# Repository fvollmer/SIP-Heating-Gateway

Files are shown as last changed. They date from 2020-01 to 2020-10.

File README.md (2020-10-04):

SIP Heating Gateway
====================


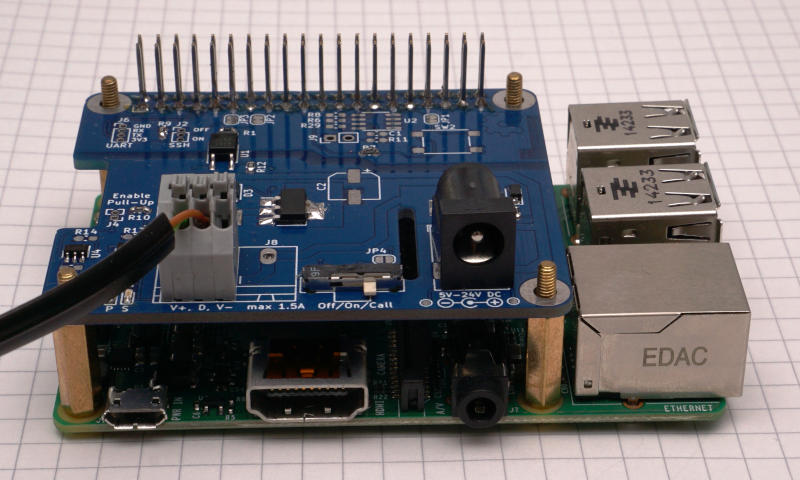
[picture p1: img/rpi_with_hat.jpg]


This device allows you to control the heating (or any other device) by calling in and using an interactive voice menu. In case of a power loss the last state will be restored as soon as the power is back. The software is build to survive unexpected power losses.

The heart of the system is a Raspberry pi with a custom hat to provide 12V to an external relay. On this Raspberry pi a custom embedded linux is used to to control the 12V via a small shell script. It connects via ethernet to the a SIP server (e.g. a fritzbox router or your isp). The heavy lifting for the SIP connection and the voice menu is done by asterisk, which uses the already mentioned shell script to switch a gpio pin. The linux system is build with buildroot and the hole image image is less than 200MB and boots in a few seconds.

The linux system on the raspberry pi is configured to use the micro sd card as read only storage. This should prevent damage on power failure. The only exception is a persitent partition, which is used to save the current state. This state will be restored in case of a power failure. The partition should also be safe from corruption due to the mount parameters and the infrequent writes.

## Usage

Connect Power (5V via micro-USB and 12V), ethernet and the output to the relay. After bootup the device accepts incoming calls.

Call the device,  wait until pickup and follow the voice instructions:
1. Enter the PIN and press `#`
2. Press `1` to turn the heating on, `2` to turn the heating off, `3` to get the status of the heating
3. Repeat step 2, or hang up

After a timeout the caller will be disconnected automatically.

```
                                               5V (micro USB)
                                                |
                                                v
+-----------------+                      +----------------+              +----------+
| router / switch | SIP (over ethernet)  | Raspberry Pi   | 12V Switched | Relay of |
| e.g. fritzbox   |<-------------------->| (with 12V hat) |------------->| heating  |
+-----------------+                      +----------------+              +----------+
                                                ^
                                                |
                                              12 V
```

## Configuration
The custom embedded system is based on buildroot. The behaviour at a call is controlled by [Asterisk](https://www.asterisk.org/). There are two main configuration files:
 * `/etc/asterisk/sip.conf`
   SIP server configuration
 * `/etc/asterisk/extensions.conf`
   Dialplan (phone menu, pin)

The configuration files can be adjusted by changing the files of the overlay (`br-external/board/raspberrypi-heating-control/rootfs-overlay`). Asterisk is configured to only use a minimal amount of modules. Modify `/etc/asterisk/modules.conf` if necessary.

There is a watchdog script (`/opt/heatingControl/asterisk_wdog`) that monitors the peers and registry and will restart asterisk in case of failures. It is automatically started at boot via `/etc/init.d/S55asterisk_wdog`. You probably want to stop it to configure asterisk and start it after the finished configuration.

For maintenace and debugging it is possible to connect to the device via a serial connection (115200 8N1) or HDMI. The system is by default read-only. To modify the file system it has to be remounted (`mount -o remount,rw /`). The login data is:

 * username: "root"
 * password: "" (There is no root password. This is no problem, because there is no way to login remotely)

## How to build the sd card image
You can build the sd card image yourself by cross compiling it on your pc. Depending on your hardware configuration this may take a while. Simply follow these steps:
1. Clone repository (use `--recursive` to get buildroot submodule)
2. Change into software folder (`cd software`)
3. `make BR2_EXTERNAL=$PWD/br-external -C buildroot raspberrypi23-heating-control_defconfig`
4. `make -C buildroot`
5. write `buildroot/output/images/sdcard.img` to sd card (e.g. `dd if=buildroot/output/images/sdcard.img of=/dev/mmcblk0 bs=1M && sync`)

## Hardware
You don't need any special hardware for this. The raspberry pi will just toggle one of the GPIO PINs (see `/opt/heatingControl/controlheating` for details).

The author of this project wants to switch a 12V relay and has designed a hat for this task. This hat is designed to take quite a bit of abuse like e.g. short circuit, reverse power, ESD etc. and can supply 5-24V with up to 1.5A from an external power supply. In practice it should also tolerate higher voltages and currents, but you probably want to check the schematic and datasheets to push the limits. Further it has a manual override switch in case of software issues or a failure of the raspberry pi. Simplified schematic:



Full schematic:



The hardware is designed to fit nicely into a HighPi Case, which has all necessary cutouts and can be mounted on a wall.

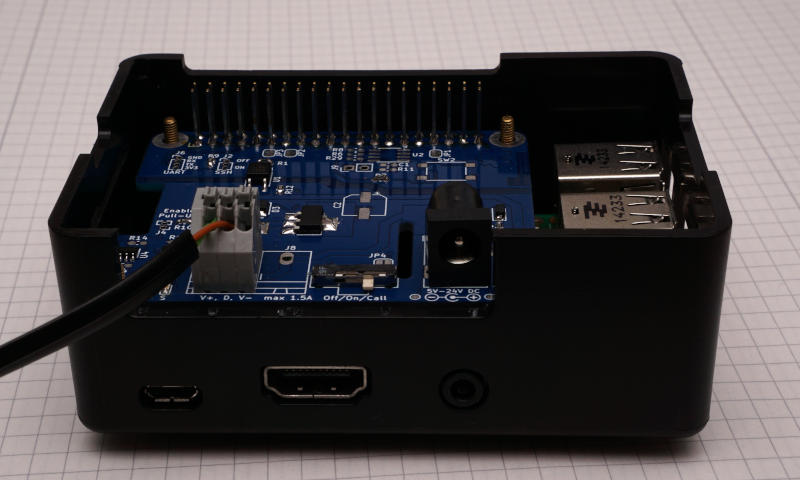
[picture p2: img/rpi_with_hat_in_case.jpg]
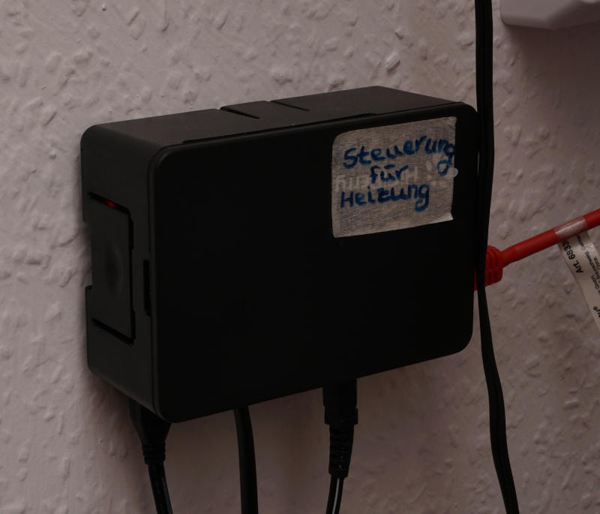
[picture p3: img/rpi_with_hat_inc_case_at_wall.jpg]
 

## Good to know
 * This system uses [Buildroot](https://buildroot.org/) to create a custom embedded system. This provides more flexibility and allows more customization than a stripped down raspbian. The complete image is just a little bigger than 100MB.
 * Connect via 3.3V serial (115200 8N1) or connect an external monitor via HDMI and use a usb keyboard
 * The heating control script is `/opt/heatingControl/controlheating`
 * The root system is read only. It can be mounted as rw (`mount / -o remount,rw`), but this is mainly recommanded for testing and maybe the initial configuration. Every change can be integrated into `br-external`. This way the image can be build in a repeatable way.
 * There is a small persistent storage partition at the sd card. It is mounted at boot via fstab at `/media/persistent/`. The mount options `rw,sync,data=journal,barrier=1,noatime,commit=1` were choosen to avoid data corruption and wear of the sd card. It is only used to store store the current state at `/media/persistent/last_state` and to restore it after a power loss. On every boot `/etc/init.d/S10restorestate` tries to restore the last state. 
 * To debug problems with asterisk it might be useful to connect to a running asterisk in verbose mode: `asterisk -rvvvv`. You can enable SIP debug mode with `sip set debug on`.
 * Any file can be added/overwritten by adding it ot the rootfs overlay at `br-external/board/raspberrypi2-heating-control/rootfs-overlay/`. 
 * The asterisk configuration files can be found at `/etc/asterisk`. The build process automatically deploys the default configuration files. The overlay is used to overwrite them.
    - SIP configuration file: `/etc/asterisk/sip.conf`
    - Dialplan (phone menu, pin): `/etc/asterisk/extensions.conf`
 * The buildroot configuration is based on the raspberry pi 2 configuration with additions to make it compatible with the raspberry pi 3. Other version can easily be added.
 * eth0 is managed by ifplugd (provided by busybox), which will automatically ifup/ifdown the interface if a network cable is connected/disconnected
 * The dhcp client was configured to run in the background. This is useful if the network link isn't ready when we try to get an ip address. This archived with a custom busybox configuration with the option `CONFIG_IFUPDOWN_UDHCPC_CMD_OPTIONS=-R -b -O search"`. The option `-b` sets udhcpc to run in the background. (`-R` is release on exit, `-O search` enables domain search option RFC 3397)
 * Busybox is configured to ship non default packages:
   - `rx` (in case we want to transfer a file via serial) 
   - `ifplugd` (see above)
 * Aterisk logs to syslog, this avoids filling up our tmpfs. Further cdr (call detail record) is disabled (`/etc/asterisk/cdr.conf`). Busybox rotates syslog for us (CONFIG_FEATURE_ROTATE_LOGFILE)
 * The hardware watchdog of the raspberry pi (bcm2835_wdt) is used to restart the system in case the system locks up. `/etc/init.d/S15watchdog` starts the watchdog at boot and periodically writes to `/dev/watchdog`.

## Overview of files
```
├──.github/workflows
├──audio-gen
├──hardware
└──software
   ├──buildroot
   └──br-external
      ├── board
      │   └── raspberrypi2-heating-control
      │       ├── genimage-raspberrypi2-heating-control.cfg
      │       ├── post-build.sh
      │       ├── post-image.sh
      │       └── rootfs-overlay
      │           └── <config files and scripts>
      ├── Config.in
      ├── configs
      │   └── raspberrypi2-heating-control_defconfig
      ├── external.desc
      └── external.mk
```

 * `.github/workflows` automatic build files
 * `audio-gen` infos about the audio file generation for the interactive voice menu
 * `hardware` pcb files for the 12V hat
 * `buildroot` git submodule of [buildroot](https://buildroot.org/)
 * `br-external` external overlay module for buildroot with all configuration and software files to build our custom linux

## Test cases

After making changes to the image, I like to test and verify that nothing broke by accident. The following test cases prooved to be useful. For now testing is done manually, but it would be an interesting idea to automate them.

 * Check basic functionality
   1. Start Rasbperry Pi with everything connected (including network)
   2. Call and interact with the voice menu
   3. Check authentication, automatic timeout, turn heating on/off, check status of heating
 * Check if state is restored on power loss
   1. Start Rasbperry Pi with everything connected (including network)
   2. Turn heating on
   3. Disconnect power, reconnect power
   4. Check if heating is automatically turned on while booting
   5. Repeat for heating off
 * Simulate power outage
   1. Disconnect Raspberry Pi AND the network infrastructure power
   2. Reconnect everything to power
   3. Check if Raspberry Pi can be called
 * Start Raspberry Pi without network and connect it later
   1. Start Raspberry Pi without network connection
   2. Wait 5 minutes
   3. Connect network connection
   4. Wait 5 minutes (asterisk watch dog will restart asterisk after like 4 minutes)
   5. Check if Raspberry Pi can be called

The previous checks are usually enough, but here are some more:

 * Check ifplugd
   1. Disconnect ethernet cable from running Pi
   2. Check if `ifconfig` if ip address is gone (takes a few seconds)
   3. Reconnect ethernet cable
   4. Check with `ifconfig` if we get a dhcp lease
 * Check asterisk watchdog
   1. Note current PID of asterisk: `pgrep -x asterisk`
   2. Disconnect ethernet cable from running Pi
   3. Check if watchdog complains at syslog (`/var/log/messages`), watchdog only checks asterisk once every 60 seconds
   4. Check if watchdog restarts asterisk after about 4 minutes by comparing the PID
 * Check if syslog is rotated
   1. run `while true; do logger hello; done` for some moments
   2. check if `/var/log/messages` is rotated to `/var/log/messages.0` and if file size is small (like 200kB)

## Enhancement Ideas
 * Add an ssh server to make maintenance easier (at the moment you have to connect via serial or connect your Keyboard and display directly). This ssh server could be enabled by a jumper to enable a maintenance mode.
 * Don't run asterisk as root. This sounds simple in theory, but the user needs permissions to write to /sys/class/gpio. The best way to archive this is probably to use `mdev` together with the `devtmpfs`. On the other hand it won't enhance the security a lot, since asterisk is the only service on this device.

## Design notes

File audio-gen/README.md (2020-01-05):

The audio at `br-external/board/raspberrypi2-heating-control/rootfs-overlay/usr/lib/asterisk/sounds` files were generated with the voice Hans from Amazon Polly. (The pricing of Amazon Polly was pretty reasonable).

The file `audio.txt` contains all used phrases. The audio files were converted from `mp3` to `sln` with `conversion.sh`.

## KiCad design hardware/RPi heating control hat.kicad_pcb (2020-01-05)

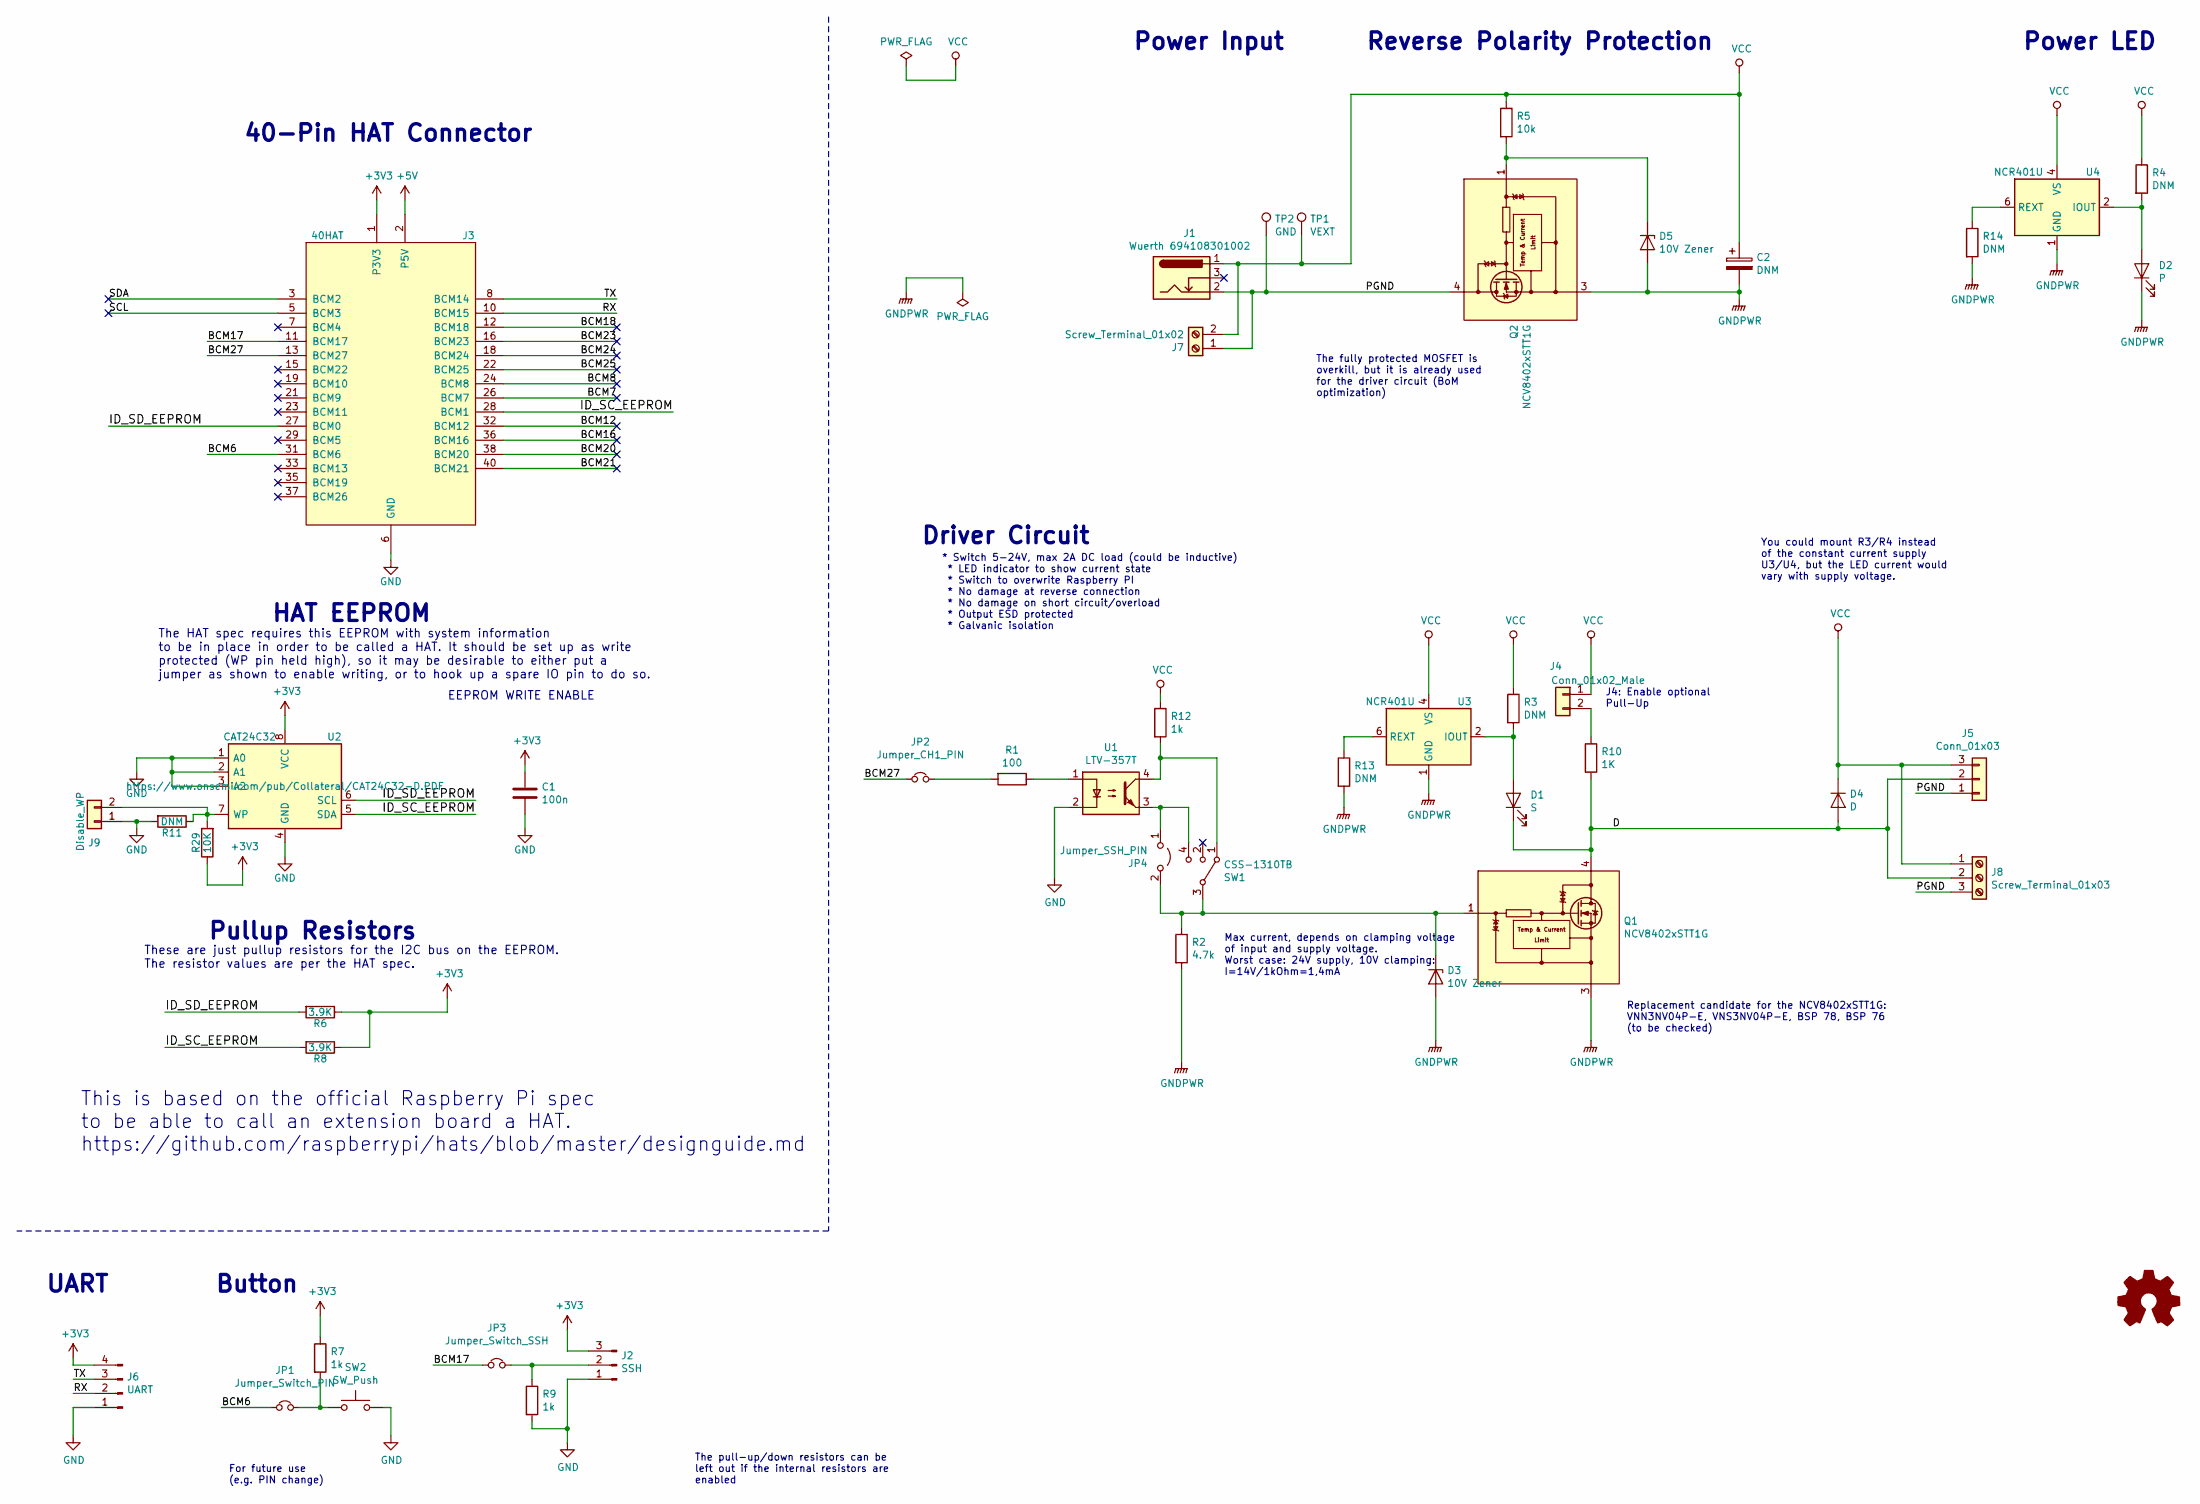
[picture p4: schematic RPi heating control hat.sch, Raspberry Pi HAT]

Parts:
C1: 100n; C_0603_1608Metric_Pad1.05x0.95mm_HandSolder
C2: DNM; CP_Elec_6.3x7.7
D1: S; LED_0603_1608Metric_Castellated; Digikey# 732-4971-1-ND
D2: P; LED_0603_1608Metric_Castellated; Digikey# 732-4978-1-ND
D3, D5: 10V Zener; D_SOD-123; Digikey# BZT52C10-TPMSCT-ND
D4: D; D_SMB-SMC_Universal_Handsoldering; Digikey# MBRS340T3GOSCT-ND
J1: Wuerth 694108301002; BarrelJack_Wuerth_6941xx301002; Digikey# 732-5934-ND
J2: SSH; PinHeader_1x03_P1.27mm_Vertical
J3: 40HAT; Raspberry_Pi_Addon_THT_With_Cutouts; Digikey# ?
J4: Conn_01x02_Male; PinHeader_1x02_P1.27mm_Vertical
J5: Conn_01x03; WAGO_250-403_1x03_P2.5
J6: UART; PinHeader_1x04_P1.27mm_Vertical
J7: Screw_Terminal_01x02; PhoenixContact_MSTBA_2,5_2-G_1x02_P5.00mm_Horizontal; Digikey# 277-1117-ND, 277-1000-ND
J8: Screw_Terminal_01x03; PhoenixContact_MSTBA_2,5_3-G_1x03_P5.00mm_Horizontal; Digikey# 277-1107-ND, 277-1012-ND
J9: Disable_WP; PinHeader_1x02_P2.54mm_Vertical
JP1: Jumper_Switch_PIN; SolderJumper-2_P1.3mm_Bridged_RoundedPad1.0x1.5mm
JP2: Jumper_CH1_PIN; SolderJumper-2_P1.3mm_Bridged_RoundedPad1.0x1.5mm
JP3: Jumper_Switch_SSH; SolderJumper-2_P1.3mm_Bridged_RoundedPad1.0x1.5mm
JP4: Jumper_SSH_PIN; SolderJumper-2_P1.3mm_Open_RoundedPad1.0x1.5mm
LOGO1: Logo_Open_Hardware_Small; OSHW-Symbol_6.7x6mm_Copper
Q1, Q2: NCV8402xSTT1G; SOT-223; Digikey# NCV8402ASTT1GOSCT-ND
R1: 100; R_0603_1608Metric_Pad1.05x0.95mm_HandSolder
R2: 4.7k; R_0603_1608Metric_Pad1.05x0.95mm_HandSolder
R3, R4, R11, R13, R14: DNM; R_0603_1608Metric_Pad1.05x0.95mm_HandSolder
R5: 10k; R_0603_1608Metric_Pad1.05x0.95mm_HandSolder
R6, R8: 3.9K; R_0603_1608Metric_Pad1.05x0.95mm_HandSolder
R7, R9, R12: 1k; R_0603_1608Metric_Pad1.05x0.95mm_HandSolder
R10: 1K; R_0603_1608Metric_Pad1.05x0.95mm_HandSolder
R29: 10K; R_0603_1608Metric_Pad1.05x0.95mm_HandSolder
SW1: CSS-1310TB; CSS-131XB; Digikey# 563-1095-1-ND
SW2: SW_Push; SW_Push_1P1T_NO_6x6mm_H9.5mm
TP1: VEXT; TestPoint_Pad_D1.0mm
TP2: GND; TestPoint_Pad_D1.0mm
U1: LTV-357T; SO-4_4.4x3.6mm_P2.54mm; Digikey# 160-1339-1-ND
U2: CAT24C32; SOIC-8_3.9x4.9mm_P1.27mm; Digikey# CAT24C32WI-GT3CT-ND
U3, U4: NCR401U; SC-74-6_1.5x2.9mm_P0.95mm; Digikey# 1727-2253-1-ND

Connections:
+3V3: C1.1, J2.3, J3.1 (P3V3), J3.17 (P3V3), J6.4, R6.1, R7.1, R8.1, R29.1, U2.8 (VCC)
+5V: J3.2 (P5V), J3.4 (P5V)
/BCM6: J3.31 (BCM6), JP1.1
/BCM7: J3.26 (BCM7)
/BCM8: J3.24 (BCM8)
/BCM12: J3.32 (BCM12)
/BCM16: J3.36 (BCM16)
/BCM17: J3.11 (BCM17), JP3.1
/BCM18: J3.12 (BCM18)
/BCM20: J3.38 (BCM20)
/BCM21: J3.40 (BCM21)
/BCM23: J3.16 (BCM23)
/BCM24: J3.18 (BCM24)
/BCM25: J3.22 (BCM25)
/BCM27: J3.13 (BCM27), JP2.1
/D: D1.1 (K), D4.2 (A), J5.2, J8.2, Q1.2 (D), Q1.4 (D), R10.2
/ID_SC_EEPROM: J3.28 (BCM1), R8.2, U2.5 (SDA)
/ID_SD_EEPROM: J3.27 (BCM0), R6.2, U2.6 (SCL)
/PGND: J1.2, J5.1, J7.1, J8.3, Q2.2 (D), Q2.4 (D), TP2.1
/RX: J3.10 (BCM15), J6.2
/SCL: J3.5 (BCM3)
/SDA: J3.3 (BCM2)
/TX: J3.8 (BCM14), J6.3
GND: C1.2, J2.1, J3.6 (GND), J3.9 (GND), J3.14 (GND), J3.20 (GND), J3.25 (GND), J3.30 (GND), J3.34 (GND), J3.39 (GND), J6.1, J9.1, R9.2, R11.2, SW2.2, U1.2, U2.1 (A0), U2.2 (A1), U2.3 (A2), U2.4 (GND)
GNDPWR: C2.2, D2.1 (K), D3.2 (A), D5.2 (A), Q1.3 (S), Q2.3 (S), R2.2, R13.2, R14.2, U3.1 (GND), U4.1 (GND)
unnamed: D1.2 (A), R3.2, U3.2 (IOUT), U3.3 (IOUT), U3.5 (IOUT)
unnamed: D2.2 (A), R4.2, U4.2 (IOUT), U4.3 (IOUT), U4.5 (IOUT)
unnamed: D3.1 (K), JP4.2 (B), Q1.1 (G), R2.1, SW1.3
unnamed: D5.1 (K), Q2.1 (G), R5.2
unnamed: J2.2, JP3.2, R9.1
unnamed: J4.2, R10.1
unnamed: J9.2, R11.1, R29.2, U2.7 (WP)
unnamed: JP1.2, R7.2, SW2.1
unnamed: JP2.2, R1.2
unnamed: JP4.1 (A), SW1.4, U1.3
unnamed: R1.1, U1.1
unnamed: R12.2, SW1.1, U1.4
unnamed: R13.1, U3.6 (REXT)
unnamed: R14.1, U4.6 (REXT)
VCC: C2.1, D4.1 (K), J1.1, J4.1, J5.3, J7.2, J8.1, R3.1, R4.1, R5.1, R12.1, TP1.1, U3.4 (VS), U4.4 (VS)

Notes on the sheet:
EEPROM WRITE ENABLE
Pullup Resistors
HAT EEPROM
40-Pin HAT Connector
The HAT spec requires this EEPROM with system information to be in place in order to be called a HAT. It should be set up as write protected (WP pin held high), so it may be desirable to either put a jumper as shown to enable writing, or to hook up a spare IO pin to do so.
These are just pullup resistors for the I2C bus on the EEPROM. The resistor values are per the HAT spec.
This is based on the official Raspberry Pi spec to be able to call an extension board a HAT. https://github.com/raspberrypi/hats/blob/master/designguide.md
UART
Power LED
Power Input
Driver Circuit
Replacement candidate for the NCV8402xSTT1G: VNN3NV04P-E, VNS3NV04P-E, BSP 78, BSP 76 (to be checked)
* Switch 5-24V, max 2A DC load (could be inductive) * LED indicator to show current state * Switch to overwrite Raspberry PI * No damage at reverse connection * No damage on short circuit/overload * Output ESD protected * Galvanic isolation
You could mount R3/R4 instead of the constant current supply U3/U4, but the LED current would vary with supply voltage.
Reverse Polarity Protection
Button
The fully protected MOSFET is overkill, but it is already used for the driver circuit (BoM optimization)
For future use (e.g. PIN change)
The pull-up/down resistors can be left out if the internal resistors are enabled
J4: Enable optional Pull-Up
Max current, depends on clamping voltage of input and supply voltage. Worst case: 24V supply, 10V clamping: I=14V/1kOhm=1,4mA

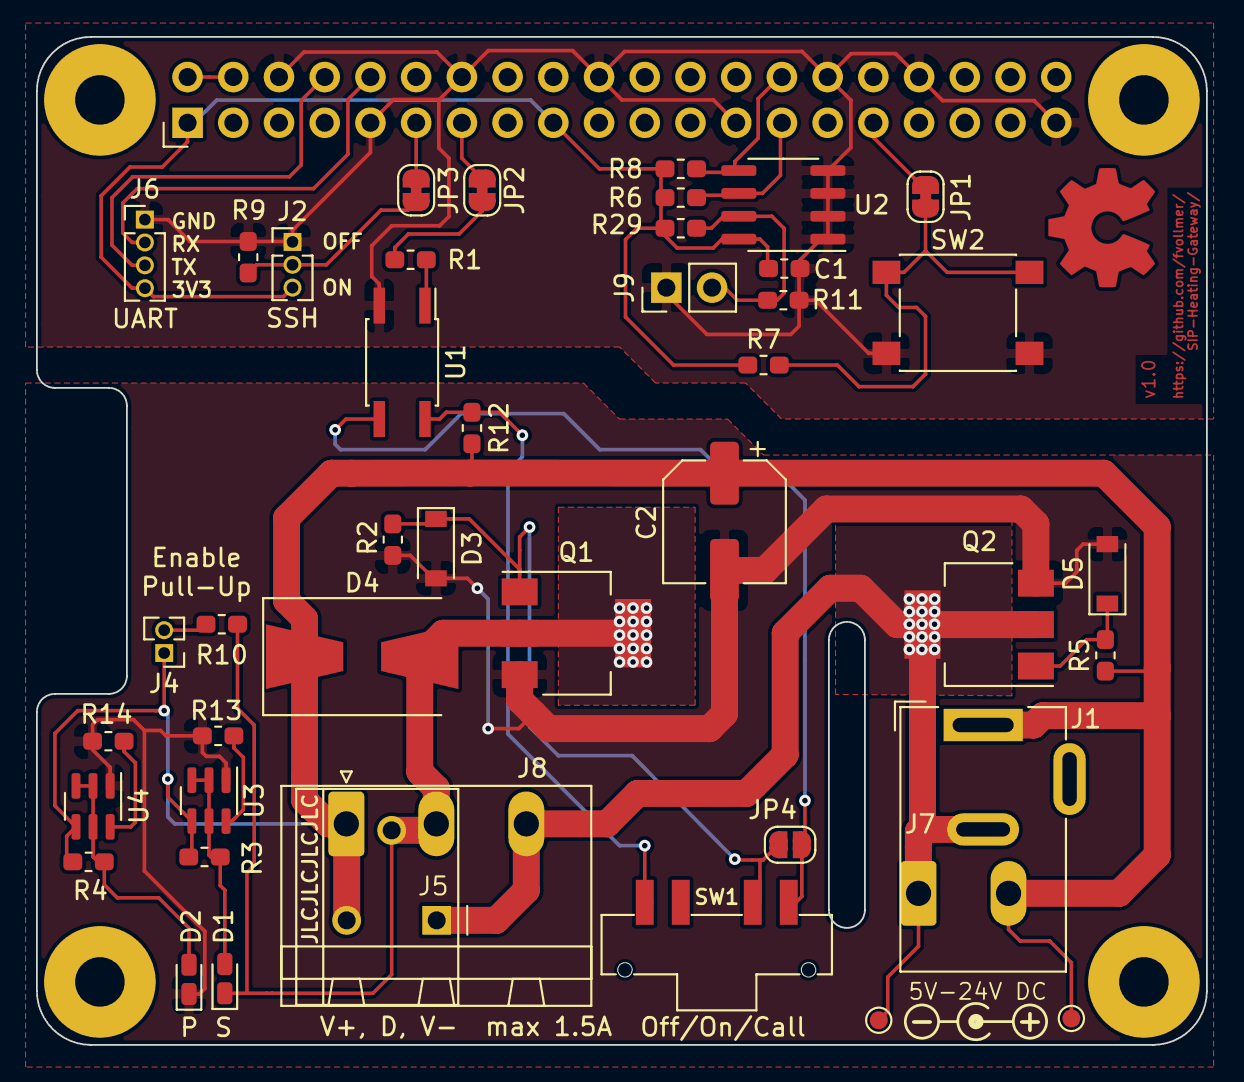
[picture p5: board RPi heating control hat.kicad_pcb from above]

Board: 2 copper layers, 65.0 x 56.0 mm, 47 parts (0 on the bottom side), 28 nets.

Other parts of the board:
Polarity_Marker: Symbol_Barrel_Polarity

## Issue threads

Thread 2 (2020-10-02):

Build on Raspberry Pi 3B+

SSStechnical, 2020-10-02:
Hi
I'm interested in getting your project running but only have a Raspberry Pi 3B+. I tried flashing the prebuilt image but this just hangs on the rainbow boot screen.
I then tried to build it but when running _**make -C buildroot**_ it gives the following error:

tmp-divrem_1.s: Assembler messages:
tmp-divrem_1.s:129: Error: selected processor does not support `mls r1,r4,r8,r11' in ARM mode
tmp-divrem_1.s:145: Error: selected processor does not support `mls r1,r4,r8,r11' in ARM mode
tmp-divrem_1.s:158: Error: selected processor does not support `mls r1,r4,r8,r11' in ARM mode
tmp-divrem_1.s:175: Error: selected processor does not support `mls r1,r4,r3,r8' in ARM mode
tmp-divrem_1.s:209: Error: selected processor does not support `mls r11,r4,r12,r3' in ARM mode
Makefile:768: recipe for target 'divrem_1.lo' failed
make[3]: *** [divrem_1.lo] Error 1
make[3]: *** Waiting for unfinished jobs....
 /usr/bin/gcc -c -DHAVE_CONFIG_H -I. -I.. -D__GMP_WITHIN_GMP -I.. -DOPERATION_sqr_basecase -I/root/SIP-Heating-Gateway/software/buildroot/output/host/include -O2 -I/root/SIP-Heating-Gateway/software/buildroot/output/host/include -Wa,--noexecstack tmp-sqr_basecase.s -fPIC -DPIC -o .libs/sqr_basecase.o
make[3]: Leaving directory '/root/SIP-Heating-Gateway/software/buildroot/output/build/host-gmp-6.1.2/mpn'
Makefile:956: recipe for target 'all-recursive' failed
make[2]: *** [all-recursive] Error 1
make[2]: Leaving directory '/root/SIP-Heating-Gateway/software/buildroot/output/build/host-gmp-6.1.2'
Makefile:775: recipe for target 'all' failed
make[1]: *** [all] Error 2
make[1]: Leaving directory '/root/SIP-Heating-Gateway/software/buildroot/output/build/host-gmp-6.1.2'
package/pkg-generic.mk:266: recipe for target '/root/SIP-Heating-Gateway/software/buildroot/output/build/host-gmp-6.1.2/.stamp_built' failed
make: *** [/root/SIP-Heating-Gateway/software/buildroot/output/build/host-gmp-6.1.2/.stamp_built] Error 2
make: Leaving directory '/root/SIP-Heating-Gateway/software/buildroot'

Are you able to advise on what changes I need to make to get this to compile correctly?

fvollmer, 2020-10-02:
Hi,

it shouldn't be hard to get this running on a Raspberry Pi 3b+, but I simply havn't tried it. I can try to add a build config.

Could you please tell me **all** the steps you did to compile and your OS? I need this info to reproduce your error message.

SSStechnical, 2020-10-02:
Hi, thanks for your help with this

cat /etc/os-release gives:
PRETTY_NAME="Raspbian GNU/Linux 9 (stretch)"
NAME="Raspbian GNU/Linux"
VERSION_ID="9"
VERSION="9 (stretch)"
VERSION_CODENAME=stretch
ID=raspbian
ID_LIKE=debian
HOME_URL="http://www.raspbian.org/"
SUPPORT_URL="http://www.raspbian.org/RaspbianForums"
BUG_REPORT_URL="http://www.raspbian.org/RaspbianBugs"

I ran _apt update_ and _apt upgrade_;
Then followed your _How To Build The SD Card Image_ steps:

1. Clone repository (use --recursive to get buildroot submodule)
2. Change into software folder (cd software)
3. make BR2_EXTERNAL=$PWD/br-external -C buildroot raspberrypi2-heating-control_defconfig
4. make -C buildroot

Steps 1-3 completed successfully but 4 resulted in the error. I'm not really sure how the _make_ command works but the error seemed to be to do with the processor and I'm aware the 3B uses a different processor to the 2B

fvollmer, 2020-10-02:
Are you trying to build on a raspberry pi? I'm not sure if this is supported by buildroot and even if it is supported it would probably take forever.

I created a PR to add support for the Raspberry Pi 3 (#3). The build seems to work and you could try the build artifact from here: https://github.com/fvollmer/SIP-Heating-Gateway/suites/1280634537/artifacts/19854112 (I didn't test it). If it works I could tag a new release.

fvollmer, 2020-10-03:
It seems like my link isn't public. I'll see what I can do about this.

And I think it would be more useful to have one universal image instead of different images for every raspberry pi variant. This shouldn't be too hard. I'm just not sure about the serial console.

fvollmer, 2020-10-04:
I created a pre release which should support the raspberry pi 2 and 3 (see https://github.com/fvollmer/SIP-Heating-Gateway/releases/tag/v1.1). I currently have neither a pi2 nor a pi3 at hand and couldn't test it yet. It would be great if you could test it and report back. I would also love to hear if the serial console is working.

Regarding your build error: I didn't try to reproduce it. The intended use is crosscompiling. Building it directly on the pi is a pretty niche (and slow!) application. I think the build process works fine, because the automatic build scripts were sucessful to cross compile it on ubuntu 18.04. To avoid further confusion I added a note about cross compiling to the `README.md`.

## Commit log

2019-11-29 initial software
    [genimage-raspberrypi2-heating-control.cfg]
2019-11-29 Add licensing information and move files All files in br-external/board/raspberrypi2-heating-control/ were moved to br-external/board/raspberrypi-heating-control/ and a symlink was created to link fr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
    [genimage-raspberrypi2-heating-control.cfg]
2019-11-29 Turn heating on if last state can't be read (to be on the safe side)
2020-01-05 Add Hardware
    [RPi heating control hat-B_Cu.gbr, RPi heating control hat-B_Mask.gbr, RPi heating control hat-B_SilkS.gbr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]
2020-01-05 Minor change in simplified schematic (schematic -> circuit)
2020-01-17 Change control pin to 27 to match with pcb
2020-05-26 Fix race condition with eth0 On the Raspberry Pi the ethernet may take a few seconds to show up (it is USB based) Our custom /etc/interfaces didn't include a "wait-delay" and therfor it could happen 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
2020-05-28 add ifplugd and rx (via busybox) ifplugd is now handling eth0 to ifup/ifdown eth0 if the ethernet cable is plugged in or removed
2020-06-04 add schematic to README.md
2020-06-05 Fix version string for assets of release, print version during build The version should only be e.g. v1.0 instead of refs.tag.v1.0
2020-10-04 clean our defconfig, bump kernel version Our defconfig has now the same structure as raspberrypi2_defconfig. This should make future upgrades easier
2020-10-04 Add support for raspberry pi 3
    [genimage-raspberrypi23-heating-control.cfg]
